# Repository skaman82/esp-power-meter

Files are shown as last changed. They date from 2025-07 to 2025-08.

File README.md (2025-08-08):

# **ESP PowerMeter**

Energy logging und current/voltage meter. Solar panel tester and a Home Assistant MQTT battery sensor
---
Web Interface:
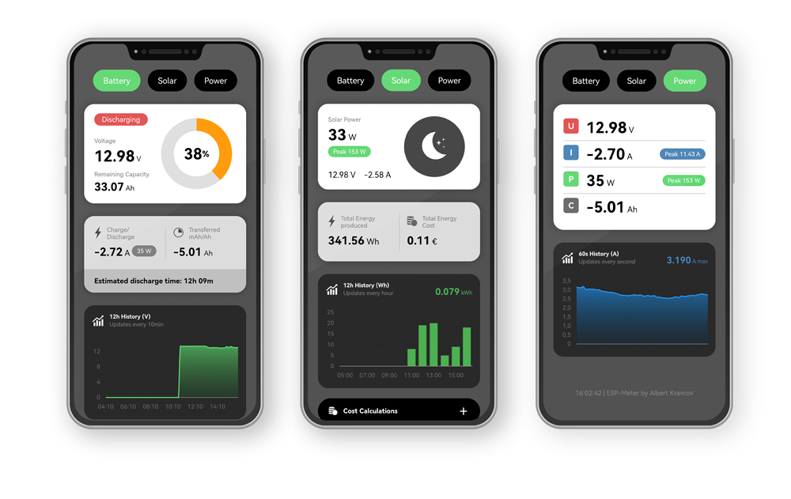
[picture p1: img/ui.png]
UI


## **Features**
- **3 Modes:** Coulometer / Solar Tester / Power Meter  
- **3 Battery Types Supported:** Li-ion, LiPo, LiFePO4  
- Fully configurable with **OLED UI**  
- **Wi-Fi Support:** Access Point mode or join an existing network  
- Additional **Web Interface**  
- **MQTT Support:** can be used as a sensor with Home Assistant  
- **Max Voltage:** 36V (listed 5V BEC supports max. 30V)  

---

## **Parts needed**
- **ESP32-C3 PRO MINI**  
- **5V BEC** (iFlight 5V 2-8S)  
- **INA226 Module** + 3920 5W 2mΩ Shunt (R002)  
 *or* custom INA226 PCB (see Hardware directory)
- **male/female XT60 connectors*
- **1.5" 128x128 I2C OLED Display** *(optional)*  
- **2x Tactile Buttons** *(optional)*
- **Real Time Clock RTC DS3231 module** *(optional)*  
- **3D Printed Case** (see STLs directory)  

## **RTC and NON-RTC Versions**
The main difference to the non-RTC version ist that the RTC version of the code uses an DS3231 real time clock for measurement and displays graph labels with the correct time in the Web-UI. 

---

Device Image:
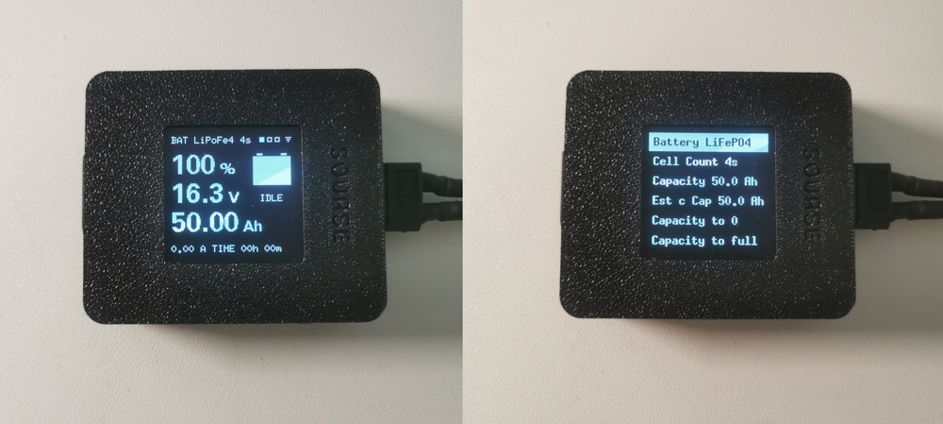
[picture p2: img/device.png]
Device


## **Button Mapping**
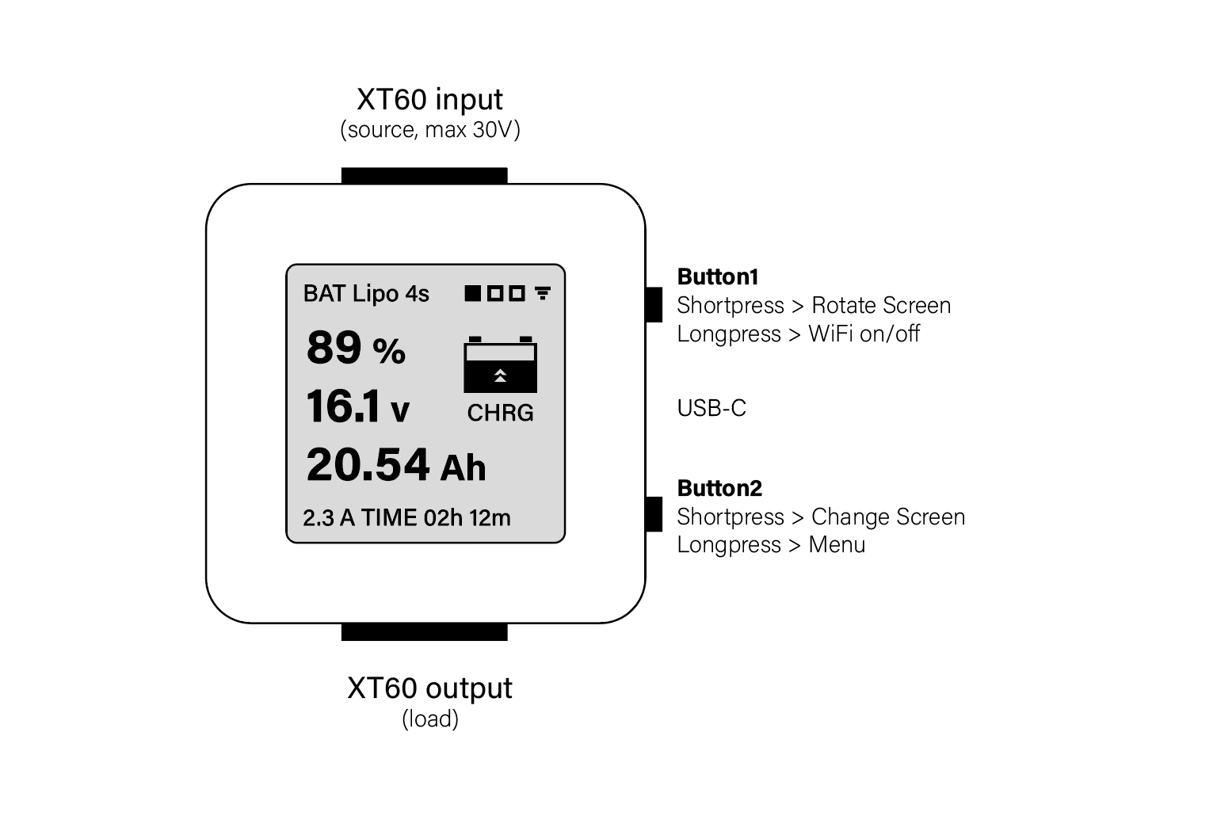
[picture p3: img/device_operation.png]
Buttons


## **MQTT Entities in Home Assistant**
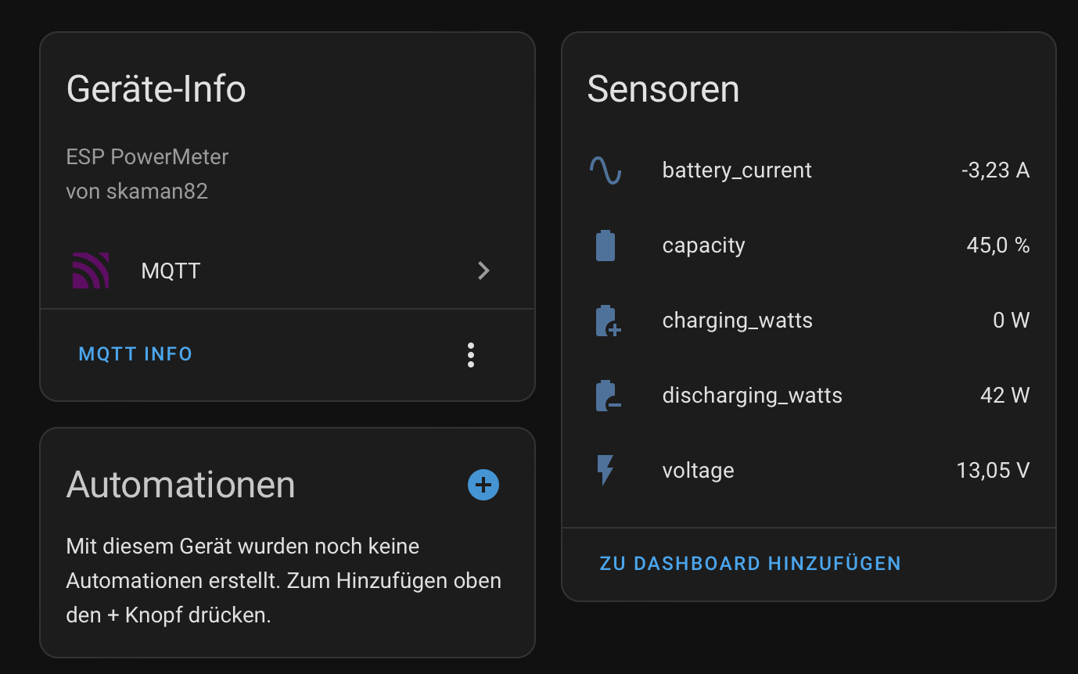
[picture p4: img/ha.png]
MQTT


Custom INA266 Sensor PCB with optional DS3231:
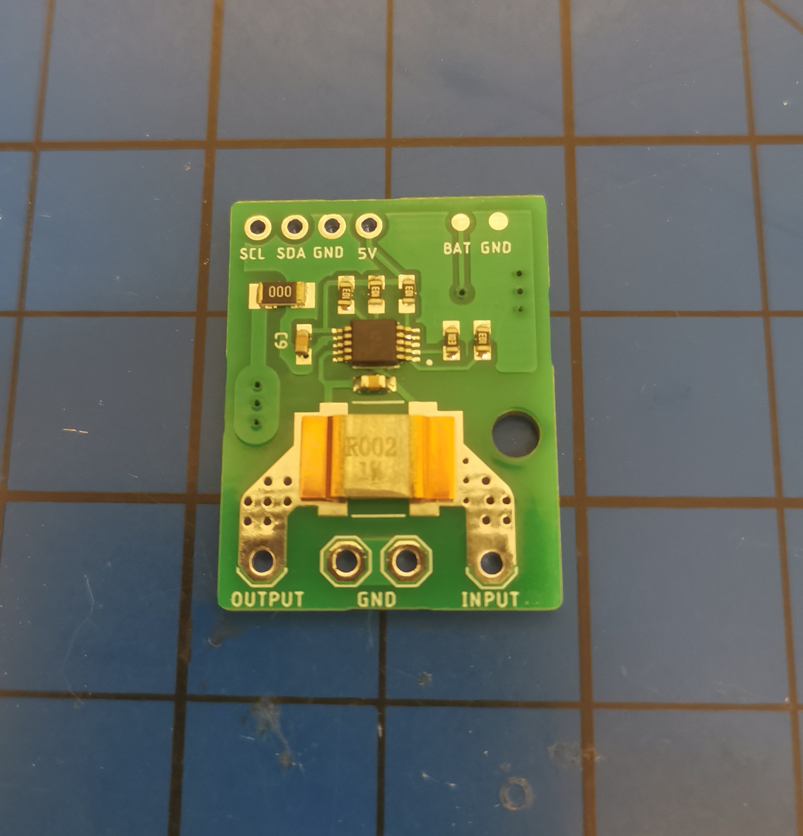
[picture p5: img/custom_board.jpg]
PCB


## **Connection Diagram**
*To be determined (TBD)*  

---

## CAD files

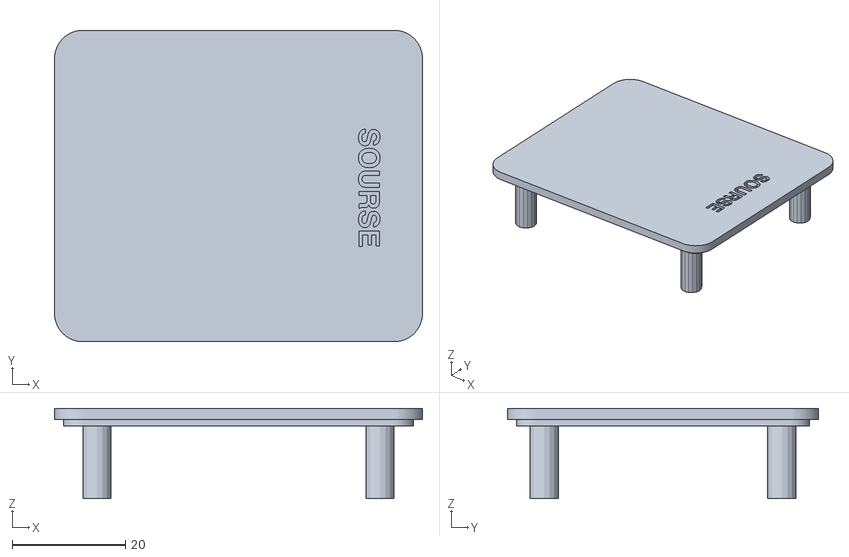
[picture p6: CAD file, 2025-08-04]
STLs/Case_cover_no_screen.stl
65.0 x 55.0 x 15.9

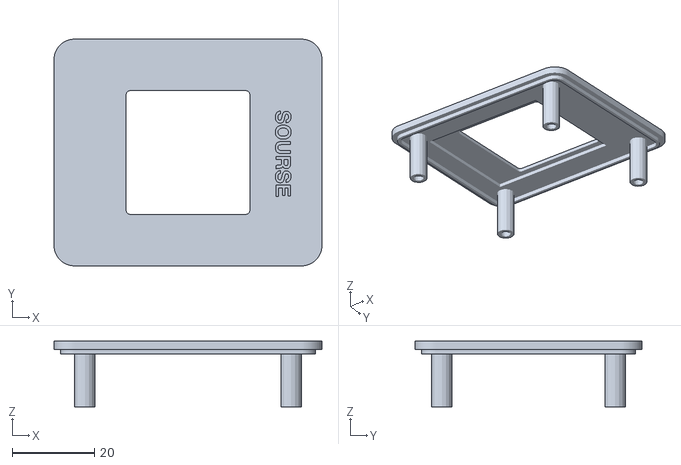
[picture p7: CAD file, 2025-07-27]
STLs/Case_cover.stl
65.0 x 55.0 x 15.9

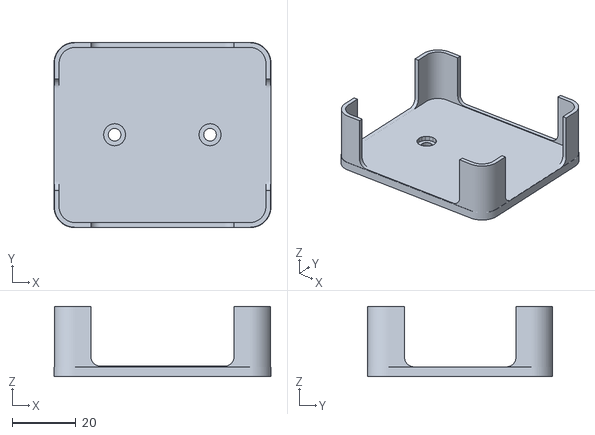
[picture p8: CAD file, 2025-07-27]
STLs/Case_holder.stl
68.2 x 58.2 x 22.0

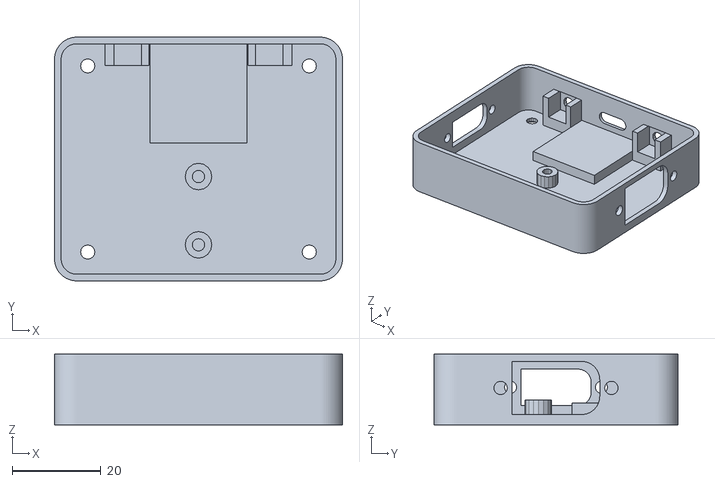
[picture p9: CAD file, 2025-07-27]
STLs/Case.stl
65.0 x 55.0 x 16.0

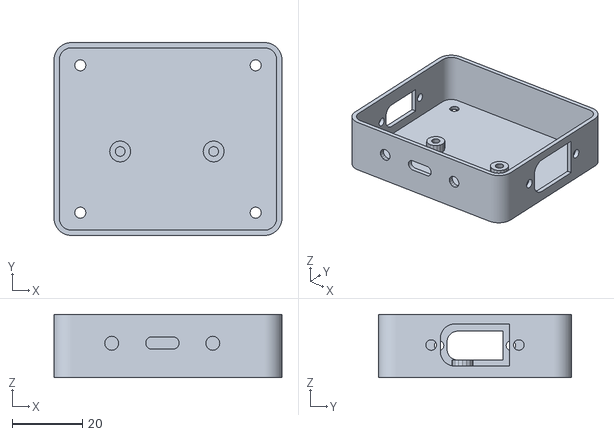
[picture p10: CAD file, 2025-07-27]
STLs/Case_allinone.stl
65.0 x 55.0 x 18.0

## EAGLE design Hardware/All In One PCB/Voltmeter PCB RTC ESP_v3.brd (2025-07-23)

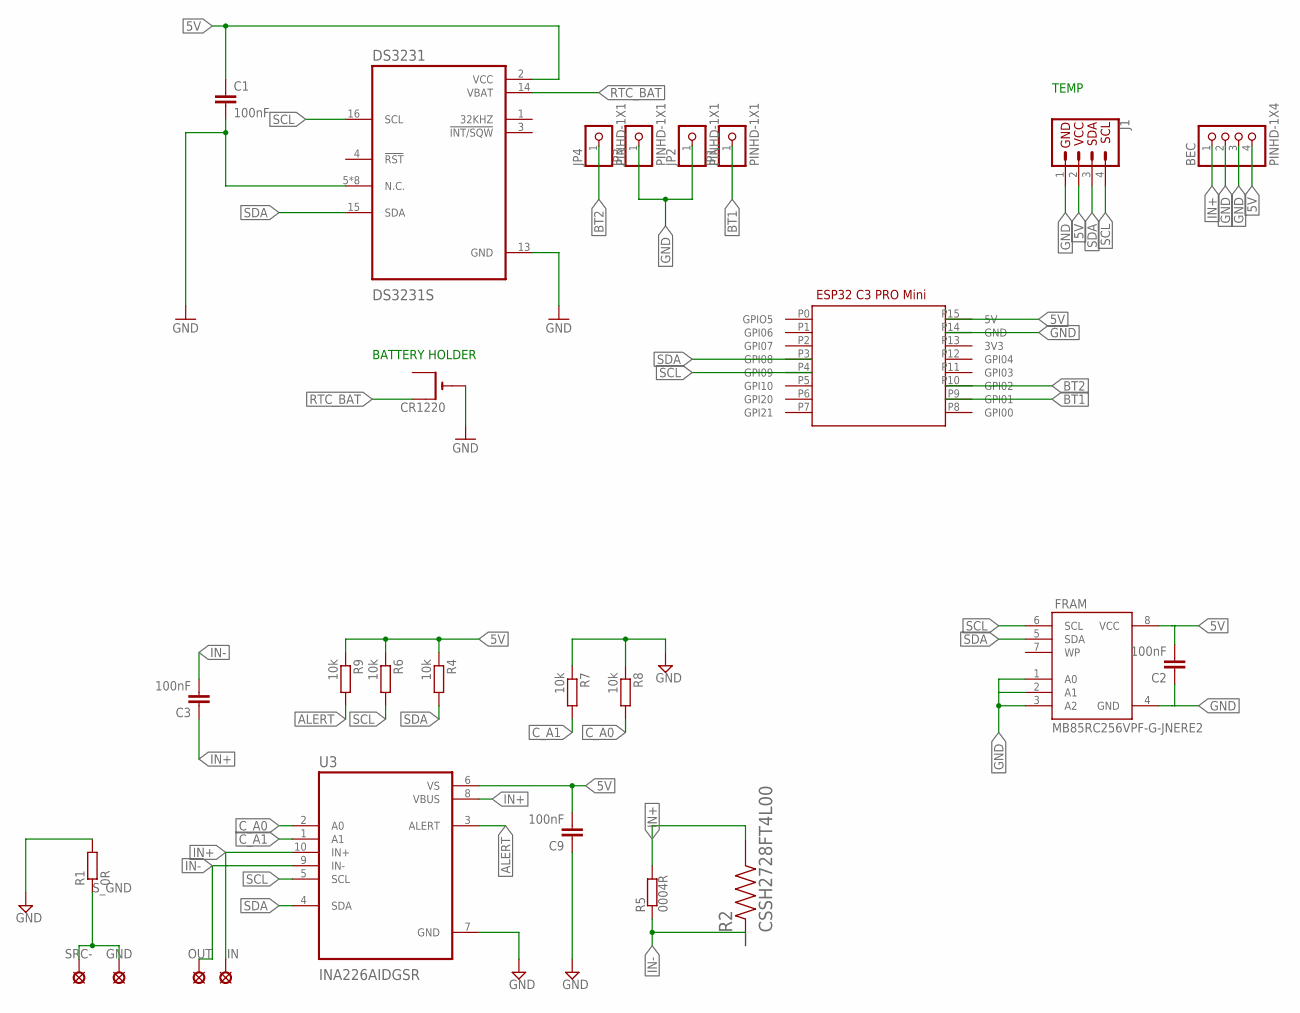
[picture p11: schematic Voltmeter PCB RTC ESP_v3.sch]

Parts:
BEC: PINHD-1X4; 1X04
C1, C2, C3, C9: 100nF; C0603
CR1220: CR1220SMT; CR1220-SMD
DS3231: DS3231S; SOIC127P1032X265-16N
FRAM: MB85RC256VPF-G-JNERE2; SOIC8_208MIL
GND: SE14
IN: SE14
J1: QWIIC_CONNECTORJS-1MM; 1X04_1MM_RA
JP1, JP2, JP3, JP4: PINHD-1X1; 1X01
OUT: SE14
R1: 0R; R1206
R2: CSSH2728FT4L00; RESC6771X124N
R4, R6, R7, R8, R9: 10k; R0603
R5: 0004R; BVS
SRC-: SE14
U3: INA226AIDGSR; SOP50P490X110-10N
U$1: ESP32_C3_PROV1; ESP32_C2_PRO

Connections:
5V: BEC.4, C1.1, C2.2, C9.2, DS3231.2 (VCC), FRAM.8 (VCC), J1.2 (VCC), R4.1, R6.1, R9.1, U3.6 (VS), U$1.P15 (5V)
ALERT: R9.2, U3.3 (ALERT)
BT1: JP1.1, U$1.P9 (GPI01)
BT2: JP4.1, U$1.P10 (GPI02)
C_A0: R8.2, U3.2 (A0)
C_A1: R7.2, U3.1 (A1)
GND: BEC.2, BEC.3, C1.2, C2.1, C9.1, CR1220.-, DS3231.5 (N.C.), DS3231.6 (N.C.), DS3231.7 (N.C.), DS3231.8 (N.C.), DS3231.9 (N.C.), DS3231.10 (N.C.), DS3231.11 (N.C.), DS3231.12 (N.C.), DS3231.13 (GND), FRAM.1 (A0), FRAM.3 (A2), FRAM.4 (GND), J1.1 (GND), JP2.1, JP3.1, R1.2, R7.1, R8.1, U3.7 (GND), U$1.P14 (GND)
IN+: BEC.1, C3.1, IN.MP, R2.2, R5.1, U3.8 (VBUS), U3.10 (IN+)
IN-: C3.2, OUT.MP, R2.1, R5.2, U3.9 (IN-)
RTC_BAT: CR1220.+$1 (+), DS3231.14 (VBAT)
SCL: DS3231.16 (SCL), FRAM.6 (SCL), J1.4 (SCL), R6.2, U3.5 (SCL), U$1.P4 (GPI09)
SDA: DS3231.15 (SDA), FRAM.5 (SDA), J1.3 (SDA), R4.2, U3.4 (SDA), U$1.P3 (GPI08)
S_GND: GND.MP, R1.1, SRC-.MP

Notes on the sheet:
BATTERY HOLDER
TEMP

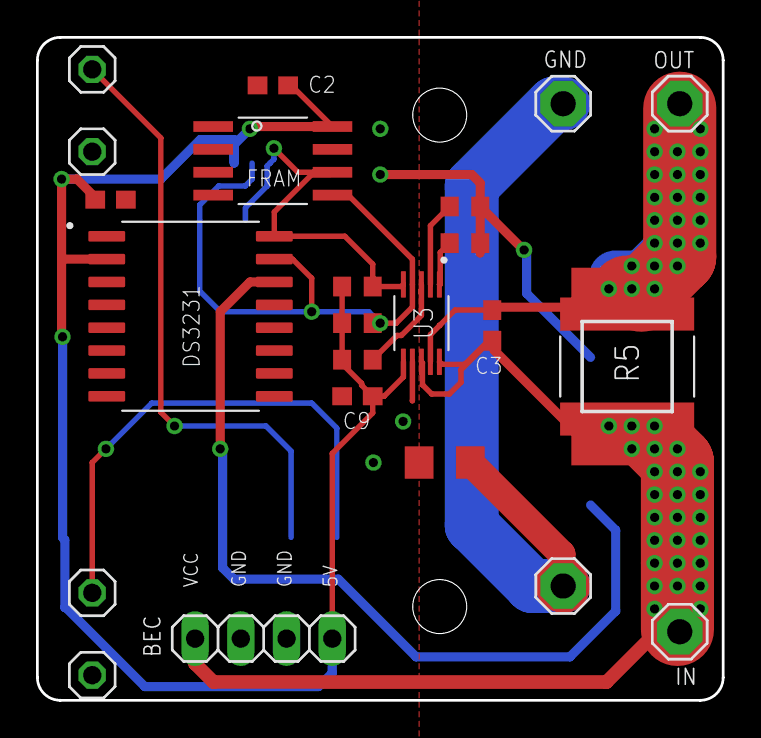
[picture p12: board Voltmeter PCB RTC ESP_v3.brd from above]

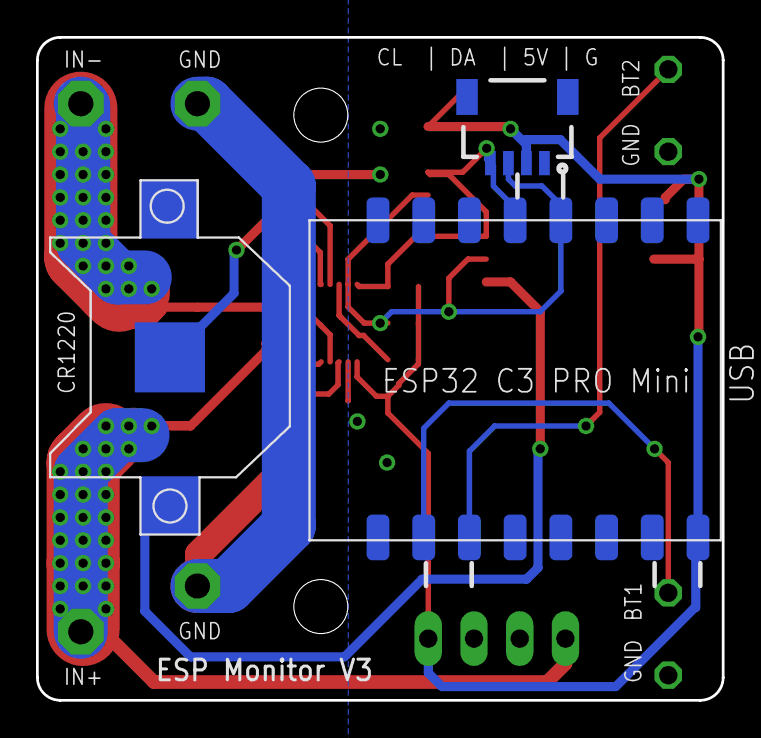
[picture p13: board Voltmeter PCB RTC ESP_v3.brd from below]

Board: 2 copper layers, 38.1 x 36.8 mm, 27 parts (3 on the bottom side), 13 nets.

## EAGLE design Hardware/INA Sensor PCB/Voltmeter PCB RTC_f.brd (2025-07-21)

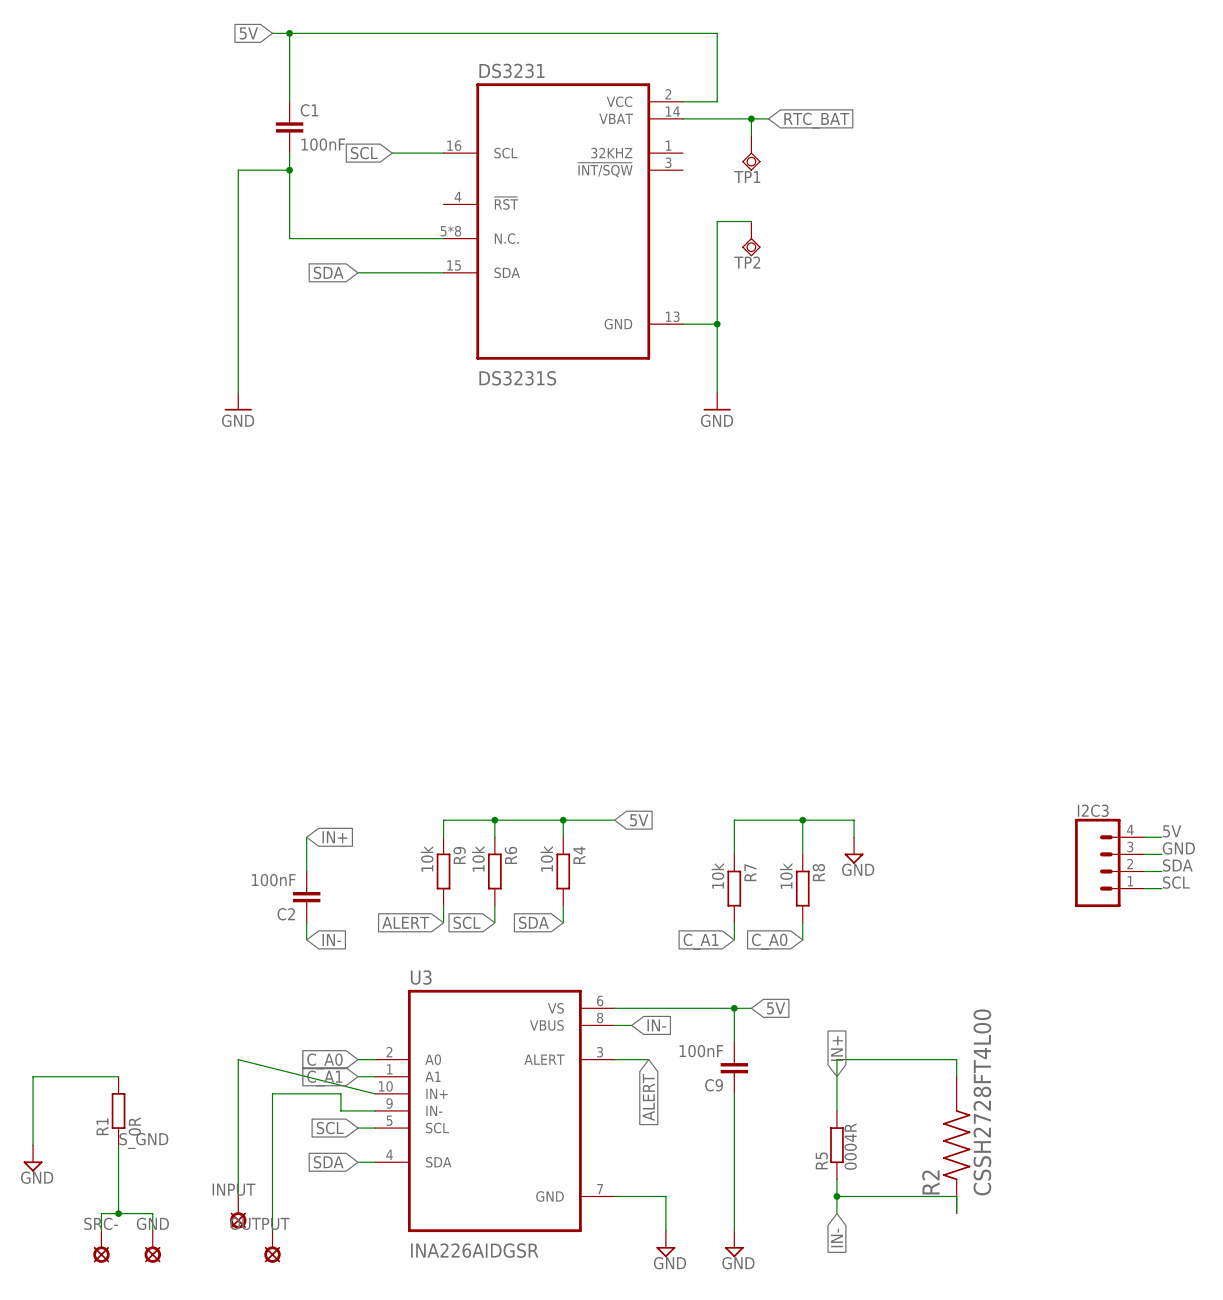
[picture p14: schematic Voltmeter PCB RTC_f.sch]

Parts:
C1, C2, C9: 100nF; C0603
DS3231: DS3231S; SOIC127P1032X265-16N
GND: SE14
I2C3: CONN_041X04_NO_SILK; 1X04_NO_SILK
INPUT: SE14
OUTPUT: SE14
R1: 0R; R1206
R2: CSSH2728FT4L00; RESC6771X124N
R4, R6, R7, R8, R9: 10k; R0603
R5: 0004R; BVS
SRC-: SE14
TP1, TP2: TPSQB1,27; B1,27
U3: INA226AIDGSR; SOP50P490X110-10N

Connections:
5V: C1.1, C9.2, DS3231.2 (VCC), I2C3.4, R4.1, R6.1, R9.1, U3.6 (VS)
ALERT: R9.2, U3.3 (ALERT)
C_A0: R8.2, U3.2 (A0)
C_A1: R7.2, U3.1 (A1)
GND: C1.2, C9.1, DS3231.5 (N.C.), DS3231.6 (N.C.), DS3231.7 (N.C.), DS3231.8 (N.C.), DS3231.9 (N.C.), DS3231.10 (N.C.), DS3231.11 (N.C.), DS3231.12 (N.C.), DS3231.13 (GND), I2C3.3, R1.2, R7.1, R8.1, TP2.TP, U3.7 (GND)
IN+: C2.2, OUTPUT.MP, R2.2, R5.1, U3.9 (IN-)
IN-: C2.1, INPUT.MP, R2.1, R5.2, U3.8 (VBUS), U3.10 (IN+)
RTC_BAT: DS3231.14 (VBAT), TP1.TP
SCL: DS3231.16 (SCL), I2C3.1, R6.2, U3.5 (SCL)
SDA: DS3231.15 (SDA), I2C3.2, R4.2, U3.4 (SDA)
S_GND: GND.MP, R1.1, SRC-.MP

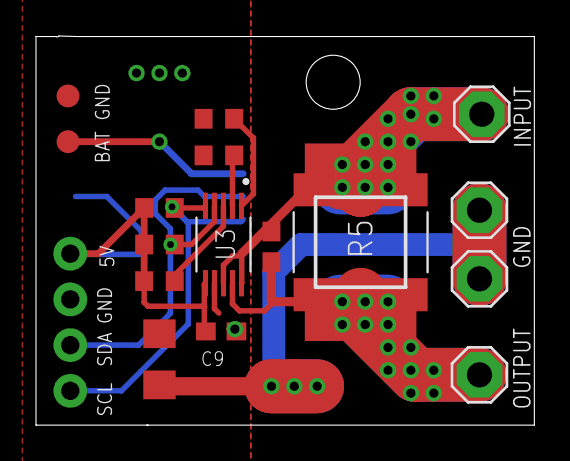
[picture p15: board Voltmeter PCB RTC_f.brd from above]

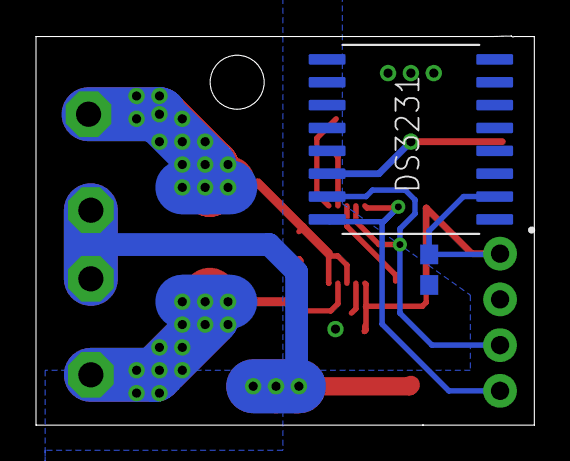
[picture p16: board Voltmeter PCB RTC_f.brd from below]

Board: 2 copper layers, 27.7 x 21.6 mm, 20 parts (2 on the bottom side), 11 nets.

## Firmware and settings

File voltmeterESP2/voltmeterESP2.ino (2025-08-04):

/** NON-RTC VERSION
 * ESP32 Power Meter - Battery Monitor System. Non-RTC Version 
 * Hardware: DFRobot Beetle ESP32-C3 @ 80MHz with INA226 current sensor
 * 
 * Features:
 * - Battery monitoring with INA226 sensor
 * - OLED display with multiple screens
 * - Web interface with real-time data
 * - MQTT integration for Home Assistant
 * - Energy consumption logging
 * - Multiple battery chemistry support (Li-ion, LiPo, LiFePO4)
 */

// ===== INCLUDES =====
#include <WiFi.h>
#include <ESPAsyncWebServer.h>
#include <ESPmDNS.h>
#include <FS.h>
#include <LittleFS.h>
#include <time.h>
#include <Preferences.h> 
#include <INA226_WE.h>
#include <Arduino.h>
#include <Wire.h>
#include <EEPROM.h>
#include <esp_system.h>

// ===== FEATURE TOGGLES =====
#define OLED                  // Enable OLED Display 
//#define MQTT                  // Enable MQTT for Home Assistant
#define WEBSERVER             // Enable Web UI

// ===== DEVICE CONFIGURATION =====
struct DeviceConfig {
    float deviceCurrent = 0.017f;        // 17 mA in normal mode
    float deviceCurrentWifi = 0.050f;    // 50 mA in WiFi Mode
    byte batteryType = 0;                // 0:LiIon; 1:LiPo; 2:LiFePO4
    int cellcount = 4;                   // Battery cell count
    float batteryCapacityAh = 50.00f;    // Full battery capacity in Ah
    byte orientation = 1;                // Screen orientation
    byte screen = 0;                     // Default start screen (0-2)
    byte wifiEnabled = 1;                // WiFi active or not
    float pricePerKWh = 0.305f;          // Price per kWh
};

// ===== NETWORK CONFIGURATION =====
const char* WIFI_SSID = "airport";
const char* WIFI_PASSWORD = "xxx";
const char* AP_PASSWORD = "12345678";

// ===== GLOBAL VARIABLES =====
DeviceConfig config;
Preferences preferences;
char AP_SSID[32];
AsyncWebServer server(80);

// ===== PIN DEFINITIONS =====
#define BUTTON1_PIN 1
#define BUTTON2_PIN 2
#define I2C_ADDRESS 0x40

// ===== HARDWARE OBJECTS =====
#ifdef OLED
#include <U8g2lib.h>
U8G2_SH1107_SEEED_128X128_F_HW_I2C u8g2(U8G2_R0, /* reset=*/ U8X8_PIN_NONE);
#endif

#ifdef MQTT
#include <PubSubClient.h>
const char* MQTT_SERVER = "homeassistant.local";
const int MQTT_PORT = 1883;
const char* MQTT_USER = "mqtt_user";
const char* MQTT_PASS = "mqtt_password";
WiFiClient espClient;
PubSubClient mqttClient(espClient);
#endif

INA226_WE ina226 = INA226_WE(I2C_ADDRESS);

// ===== TIMING VARIABLES =====
struct TimingControl {
    unsigned long previousMillis = 0;
    unsigned long lastSensorMillis = 0;
    unsigned long lastUpdateMicros = 0;
    unsigned long previousMicros = 0;
    unsigned long lastEnergySecond = 0;
    unsigned long lastMqttAttempt = 0;
    unsigned long hourStartMillis = 0;
    unsigned long lastCapacityMinuteMillis = 0;
    unsigned long lastAmpSecondMillis = 0;
    
    const unsigned long SENSOR_INTERVAL = 1000;        // 1 second
    const unsigned long INTERVAL_MICROS = 1000000;     // 1 second in microseconds
    const unsigned long MQTT_RETRY_INTERVAL = 5000;    // 5 seconds
};
TimingControl timing;

// ===== SENSOR DATA STRUCTURE =====
struct SensorData {
    float voltage = 0.0f;
    float current = 0.0f;
    float cellVoltage = 0.0f;
    float capacity = 0.0f;
    float remainingCapacityAh = 0.0f;
    int remainingCapacitymAh = 0;
    int watts = 0;
    int maxWatts = 0;
    float maxCurrent = 0.0f;
    float maxCurrentMin = 0.0f;
    byte currentDirection = 0;  // 0=idle, 1=discharging, 2=charging
    float selfConsumption = 0.0f;
    
    // Energy tracking
    float totalWh = 0.0f;
    float totalKWh = 0.0f;
    float totalPrice = 0.0f;
    float totalUsedmAh = 0.0f;
    double accumulatedWh = 0.0;
    
    // Runtime calculation
    float runtimeHours = 0.0f;
    int hours = 0;
    int minutes = 0;
};
SensorData sensorData;

// ===== UI CONTROL =====
struct UIControl {
    byte menu = 0;
    byte submenu = 0;
    byte menustep = 0;
    byte pressedButton = 0;
    
    // Button handling
    bool button1State = false;
    bool button2State = false;
    unsigned long button1PressTime = 0;
    unsigned long button2PressTime = 0;
    bool button1Handled = false;
    bool button2Handled = false;
    
    const unsigned long LONG_PRESS_TIME = 500;
    
    // Display buffers
    char batteryChars[7] = "000.00";
    char priceChars[6] = "0.000";
    
    byte saved = 0;
    byte reset = 0;
    bool statsSaved = true;
};
UIControl ui;

// ===== EEPROM ADDRESSES =====
struct EEPROMAddresses {
    static const int TYPE = 0;
    static const int CELL = 1;
    static const int CAPACITY = 2;
    static const int PRICE = 6;
    static const int REMAINING_CAP = 10;
    static const int KWH = 14;
    static const int MODE = 18;
    static const int WIFI = 19;
    static const int SCREEN = 30;
    static const int ORIENTATION = 31;
    static const int KWH_HISTORY = 32;
};

// ===== DATA ARRAYS =====
float hourlyKWh[12] = {0};          // Last 12 hours kWh values
float historyCapacity[72] = {0};     // 72 × 10min = 720min = 12h
float historyVoltage[72] = {0};      // Voltage history
float last60Amps[60] = {0};          // Last 60 seconds of amp readings
int capacityIndex = 0;

// ===== BATTERY CURVES =====
// Li-ion battery discharge curve
const int LIION_POINTS = 11;
const float liionVoltage[LIION_POINTS]  = {4.20, 4.10, 4.00, 3.90, 3.80, 3.70, 3.60, 3.50, 3.40, 3.30, 3.20};
const float liionCapacity[LIION_POINTS] = {100,   90,   80,   70,   60,   50,   40,   30,   20,   10,    0};

// LiPo battery discharge curve
const int LIPO_POINTS = 11;
const float lipoVoltage[LIPO_POINTS]  = {4.20, 4.15, 4.05, 3.95, 3.85, 3.75, 3.65, 3.55, 3.45, 3.35, 3.30};
const float lipoCapacity[LIPO_POINTS] = {100,   95,   85,   75,   65,   55,   45,   35,   20,   10,    0};

// LiFePO4 battery discharge curve
const int LIFEPO4_POINTS = 9;
const float lifepo4Voltage[LIFEPO4_POINTS]  = {3.65, 3.45, 3.40, 3.35, 3.30, 3.25, 3.20, 3.10, 2.90};
const float lifepo4Capacity[LIFEPO4_POINTS] = {100,   95,   90,   80,   60,   40,   25,   10,    0};

// ===== FUNCTION DECLARATIONS =====
void initializeSystem();
void initializeSSID();
void initializeHardware();
void initializeEEPROM();
void initializeWiFi();
void initializeWebServer();
void initializeMQTT();

void updateSensorData();
void handleButtons();
void handleEnergyLogging();
float estimateCapacity(float voltage, const float* volts, const float* caps, int size);
void saveConfigToEEPROM();

#ifdef OLED
void updateDisplay();
void drawMainScreen();
void drawPowerScreen();
void drawStatsScreen();
void drawMenuScreen();
void drawCapacityEditScreen();
void drawPriceEditScreen();
void handleButtonInput();
#endif

#ifdef MQTT
void handleMQTT();
void checkMQTTConnection();
void publishSensorData();
void publishDiscoveryMessages();
void publishDiscoveryEntity(const char* name, const char* unit, const char* deviceClass, 
                           const char* icon, const String& deviceInfo, const String& baseTopic);
#endif

void handleWebServer();
void disableWiFiServer();

// ===== MAIN SETUP FUNCTION =====
void setup() {
    Serial.begin(9600);
    Serial.println("ESP32 Power Meter Starting...");
    
    // Initialize all subsystems
    initializeSystem();
    
    Serial.println("System initialization complete!");
}

// ===== MAIN LOOP =====
void loop() {
    // Handle time-critical operations
    handleButtons();
    
    // Handle sensor reading every second
    if (millis() - timing.lastSensorMillis >= timing.SENSOR_INTERVAL) {
        timing.lastSensorMillis = millis();
        updateSensorData();
        handleEnergyLogging();
    }
    
    #ifdef OLED
    handleButtonInput();
    updateDisplay();
    #endif
    
    #ifdef MQTT
    if (config.wifiEnabled && WiFi.status() == WL_CONNECTED) {
        handleMQTT();
    }
    #endif
}

// ===== SYSTEM INITIALIZATION =====
/**
 * Initialize all system components in proper order
 */
void initializeSystem() {
    // Setup pins
    pinMode(BUTTON1_PIN, INPUT_PULLUP);
    pinMode(BUTTON2_PIN, INPUT_PULLUP);
    
    // Initialize subsystems
    initializeSSID();
    
    #ifdef OLED
    initializeEEPROM();
    #endif
    
    initializeHardware();

    if (config.wifiEnabled) {
        initializeWiFi();
        
        #ifdef MQTT
        initializeMQTT();
        #endif
        
        #ifdef WEBSERVER
        initializeWebServer();
        #endif
        
        sensorData.selfConsumption = config.deviceCurrentWifi;
    } else {
        sensorData.selfConsumption = config.deviceCurrent;
    }
    
    // Initialize data arrays
    memset(last60Amps, 0, sizeof(last60Amps));
    memset(historyCapacity, 0, sizeof(historyCapacity));
    memset(historyVoltage, 0, sizeof(historyVoltage));
    memset(hourlyKWh, 0, sizeof(hourlyKWh));
    
    // Initialize energy tracking
    timing.hourStartMillis = millis();
}

/**
 * Generate unique SSID for access point mode
 */
void initializeSSID() {
    preferences.begin("esp32meter", false);
    
    if (!preferences.isKey("ssid")) {
        randomSeed(esp_random());
        int suffix = random(100, 1000);
        snprintf(AP_SSID, sizeof(AP_SSID), "ESP32-Meter %d", suffix);
        preferences.putString("ssid", AP_SSID);
    } else {
        String storedSSID = preferences.getString("ssid", "ESP32-Meter");
        storedSSID.toCharArray(AP_SSID, sizeof(AP_SSID));
    }
    
    preferences.end();
    Serial.println("SSID: " + String(AP_SSID));
}

/**
 * Initialize all hardware components (I2C, INA226, OLED)
 */
void initializeHardware() {
    // Initialize I2C
    Wire.begin();
    
    // Initialize INA226 current sensor
    if (!ina226.init()) {
        Serial.println("ERROR: INA226 initialization failed!");
        return;
    }
    
    // Configure INA226 for optimal performance
    ina226.setAverage(AVERAGE_64);           // Average 64 samples for stability
    ina226.setMeasureMode(CONTINUOUS);       // Continuous measurement mode

    // Shunt resistor configuration - adjust based on your hardware
    // R002 = 2mΩ resistor, max ~41A measurement range
    // R004 = 4mΩ resistor, max ~20A measurement range  
    // R001 = 1mΩ resistor, max ~82A measurement range
    ina226.setResistorRange(0.00198, 20);    // R002 2mOhm resistor, max ~41A
    ina226.waitUntilConversionCompleted();

    Serial.println("INA226 sensor initialized successfully");
    
    #ifdef OLED
    // Initialize OLED display
    u8g2.begin();
    setDisplayOrientation();
    Serial.println("OLED initialized successfully");
    #endif
}

#ifdef OLED
/**
 * Set display orientation based on configuration
 */
void setDisplayOrientation() {
    switch (config.orientation) {
        case 0: u8g2.setDisplayRotation(U8G2_R1); break;
        case 1: u8g2.setDisplayRotation(U8G2_R2); break;
        case 2: u8g2.setDisplayRotation(U8G2_R3); break;
        case 3: u8g2.setDisplayRotation(U8G2_R0); break;
        default: u8g2.setDisplayRotation(U8G2_R2); break;
    }
    u8g2.clear();
}
#endif

/**
 * Load configuration from EEPROM and validate values
 */
void initializeEEPROM() {
    EEPROM.begin(512);
    Serial.println("Loading configuration from EEPROM...");
    
    // Load battery configuration
    config.batteryType = EEPROM.read(EEPROMAddresses::TYPE);
    if (config.batteryType > 2) config.batteryType = 0;
    
    config.cellcount = EEPROM.read(EEPROMAddresses::CELL);
    if (config.cellcount == 0 || config.cellcount > 6) config.cellcount = 1;
    
    // Load and validate float values
    EEPROM.get(EEPROMAddresses::CAPACITY, config.batteryCapacityAh);
    if (isnan(config.batteryCapacityAh) || config.batteryCapacityAh <= 0 || config.batteryCapacityAh > 1000) {
        config.batteryCapacityAh = 1.0f;
        EEPROM.put(EEPROMAddresses::CAPACITY, config.batteryCapacityAh);
    }
    
    EEPROM.get(EEPROMAddresses::PRICE, config.pricePerKWh);
    if (isnan(config.pricePerKWh) || config.pricePerKWh < 0 || config.pricePerKWh > 1000) {
        config.pricePerKWh = 0.0f;
        EEPROM.put(EEPROMAddresses::PRICE, config.pricePerKWh);
    }
    
    // Load UI settings
    config.wifiEnabled = EEPROM.read(EEPROMAddresses::WIFI);
    if (config.wifiEnabled > 1) {
        config.wifiEnabled = 0;
        EEPROM.write(EEPROMAddresses::WIFI, config.wifiEnabled);
    }
    
    config.screen = EEPROM.read(EEPROMAddresses::SCREEN);
    if (config.screen > 2) config.screen = 0;
    
    config.orientation = EEPROM.read(EEPROMAddresses::ORIENTATION);
    if (config.orientation > 3) config.orientation = 0;
    
    // Load sensor data
    EEPROM.get(EEPROMAddresses::REMAINING_CAP, sensorData.remainingCapacityAh);
    if (isnan(sensorData.remainingCapacityAh) || sensorData.remainingCapacityAh < 0) {
        sensorData.remainingCapacityAh = config.batteryCapacityAh;
        EEPROM.put(EEPROMAddresses::REMAINING_CAP, sensorData.remainingCapacityAh);
    }
    
    EEPROM.get(EEPROMAddresses::KWH, sensorData.totalKWh);
    if (isnan(sensorData.totalKWh) || sensorData.totalKWh < 0 || sensorData.totalKWh > 100000) {
        sensorData.totalKWh = 0.0f;
        EEPROM.put(EEPROMAddresses::KWH, sensorData.totalKWh);
    }
    
    EEPROM.commit();
    
    // Calculate derived values
    sensorData.remainingCapacitymAh = sensorData.remainingCapacityAh * 1000.0f;
    sensorData.totalWh = sensorData.totalKWh * 1000.0f;
    sensorData.totalPrice = sensorData.totalKWh * config.pricePerKWh;
    
    Serial.println("Configuration loaded successfully");
    Serial.println("Battery Type: " + String(config.batteryType));
    Serial.println("Cell Count: " + String(config.cellcount));
    Serial.println("Capacity: " + String(config.batteryCapacityAh) + " Ah");
    Serial.println("Price/kWh: " + String(config.pricePerKWh));
    Serial.println("Orientation: " + String(config.orientation));
    Serial.println("Screen: " + String(config.screen));
}

/**
 * Initialize WiFi in dual mode (AP + Station)
 */
void initializeWiFi() {
    WiFi.mode(WIFI_AP_STA);
    
    // Start Access Point
    WiFi.softAP(AP_SSID, AP_PASSWORD);
    Serial.println("Access Point: " + String(AP_SSID));
    Serial.println("AP IP: " + WiFi.softAPIP().toString());
    
    // Try to connect to existing WiFi
    WiFi.begin(WIFI_SSID, WIFI_PASSWORD);
    Serial.print("Connecting to WiFi");
    
    int retry = 0;
    while (WiFi.status() != WL_CONNECTED && retry < 20) {
        delay(500);
        Serial.print(".");
        retry++;
    }
    
    if (WiFi.status() == WL_CONNECTED) {
        Serial.println("\nWiFi connected: " + WiFi.localIP().toString());
    } else {
        Serial.println("\nWiFi connection failed - AP mode only");
    }
}

#ifdef MQTT
/**
 * Initialize MQTT client for Home Assistant integration
 */
void initializeMQTT() {
    mqttClient.setServer(MQTT_SERVER, MQTT_PORT);
    mqttClient.setKeepAlive(60);
    mqttClient.setBufferSize(512);
    Serial.println("MQTT client initialized");
}
#endif

/**
 * Initialize web server and API endpoints
 */
void initializeWebServer() {
    if (!LittleFS.begin(true)) {
        Serial.println("Failed to mount LittleFS");
        return;
    }
    
    // Serve static files
    server.serveStatic("/", LittleFS, "/").setDefaultFile("index.html");
    
    // API endpoint for sensor data
    server.on("/data", HTTP_GET, [](AsyncWebServerRequest *request) {
        String json = buildSensorDataJSON();
        request->send(200, "application/json", json);
    });
    
    // API endpoint for screen control
    server.on("/setScreen", HTTP_POST, [](AsyncWebServerRequest *request) {
        if (request->hasParam("value", true)) {
            String value = request->getParam("value", true)->value();
            config.screen = value.toInt();
            request->send(200, "text/plain", "OK");
        } else {
            request->send(400, "text/plain", "Missing 'value'");
        }
    });
    
    server.onNotFound([](AsyncWebServerRequest *request) {
        request->send(404, "text/plain", "404: Not Found");
    });
    
    server.begin();
    Serial.println("Webserver started");
}

/**
 * Build JSON string with all sensor data for web interface
 */
String buildSensorDataJSON() {
    String json = "{";
    json += "\"batteryType\":" + String(config.batteryType) + ",";
    json += "\"cellcount\":" + String(config.cellcount) + ",";
    json += "\"watts\":" + String(sensorData.watts) + ",";
    json += "\"Ampere\":" + String(sensorData.current, 2) + ",";
    json += "\"cur_dir\":" + String(sensorData.currentDirection) + ",";
    json += "\"voltage\":" + String(sensorData.voltage, 2) + ",";
    json += "\"capacity\":" + String(sensorData.capacity, 2) + ",";
    json += "\"batteryCapacityAh\":" + String(config.batteryCapacityAh, 2) + ",";
    json += "\"remainingCapacityAh\":" + String(sensorData.remainingCapacityAh, 2) + ",";
    json += "\"pricePerKWh\":" + String(config.pricePerKWh, 3) + ",";
    json += "\"totalWh\":" + String(sensorData.totalWh, 2) + ",";
    json += "\"totalKWh\":" + String(sensorData.totalKWh, 3) + ",";
    
    // Dynamic energy display
    if (abs(sensorData.totalUsedmAh) >= 1000.0f) {
        json += "\"usedEnergy\":" + String(sensorData.totalUsedmAh / 1000.0f, 2) + ",";
        json += "\"usedUnit\":\"Ah\",";
    } else {
        json += "\"usedEnergy\":" + String(sensorData.totalUsedmAh, 0) + ",";
        json += "\"usedUnit\":\"mAh\",";
    }
    
    json += "\"screen\":" + String(config.screen) + ",";
    json += "\"maxWatts\":" + String(sensorData.maxWatts) + ",";
    json += "\"maxA\":" + String(sensorData.maxCurrent, 2) + ",";
    json += "\"maxA_min\":" + String(sensorData.maxCurrentMin, 2);
    
    // Add array data
    json += ",\"hourlyKWh\":[";
    for (int i = 0; i < 12; i++) {
        json += String(hourlyKWh[i], 3);
        if (i < 11) json += ",";
    }
    json += "]";
    
    json += ",\"historyCapacity\":[";
    for (int i = 0; i < 72; i++) {
        json += String(static_cast<int>(historyCapacity[i]));
        if (i < 71) json += ",";
    }
    json += "]";
    
    json += ",\"historyVoltage\":[";
    for (int i = 0; i < 72; i++) {
        json += String(historyVoltage[i], 2);
        if (i < 71) json += ",";
    }
    json += "]";
    
    json += ",\"last60Amps\":[";
    for (int i = 0; i < 60; i++) {
        json += String(last60Amps[i], 2);
        if (i < 59) json += ",";
    }
    json += "]";
    
    json += "}";
    return json;
}
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

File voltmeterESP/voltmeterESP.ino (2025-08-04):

#include <WiFi.h>
#include <ESPAsyncWebServer.h>
#include <ESPmDNS.h>
#include <FS.h>
#include <LittleFS.h>
#include <time.h>
#include <Preferences.h>  
Preferences preferences;  // Declare this globallychar AP_SSID[32];
#include <INA226_WE.h>
#include <Arduino.h>
#include <Wire.h>
#include <EEPROM.h>
#include <esp_system.h>


//CONFIG START >>>>>>>>>>>>>>>>>>>>>>>>>>>>>>>>>>>>>>>>>>>>>>>>>>>>>>>>>>>>>>>>>>>>>>>>

#define OLED  // Enable OLED Display 
#define MQTT  // Enable MQTT for Home Assistant
#define WEBSERVER    // Enable Web UI



//Device Settings START (No need to configure when using an OLED screen and buttons)
float deviceCurrent = 0.017;      // 17 mA in normal mode
float deviceCurrentWifi = 0.050;  // 50 mA in WiFi Mode
byte batteryType = 0;             // 0:LiIon; 1:LiPo; 2:LiFePO4;
int cellcount = 4;                // define Cellcount of the Li-Ion battery
float batteryCapacityAh = 50;     // Full battery capacity in Ah eg 6.6 Ah
byte orientation = 1;             // Screen orientation
byte screen = 0;                  // default start screen (0-2)
byte wifiEnabled = 1;             // WiFi active or not
float pricePerKWh = 0.305;         // 30.5 cents per kWh

//Device Settings END 

#ifdef OLED
#include <U8g2lib.h>
//OLED SELECTION (Uncomment the right one for you)
//U8G2_SSD1306_128X64_NONAME_F_HW_I2C u8g2(U8G2_R0, /* reset=*/ U8X8_PIN_NONE);
//U8G2_SH1106_128X64_NONAME_F_HW_I2C u8g2(U8G2_R0, /* reset=*/ U8X8_PIN_NONE);
//U8G2_SH1107_PIMORONI_128X128_1_HW_I2C u8g2(U8G2_R0, /* reset=*/8);
U8G2_SH1107_SEEED_128X128_F_HW_I2C u8g2(U8G2_R0, /* reset=*/ U8X8_PIN_NONE);
#endif

// ===== NETWORK CONFIGURATION =====
const char* WIFI_SSID = "airport";
const char* WIFI_PASSWORD = "babylon5";
const char* AP_PASSWORD = "12345678";

#ifdef MQTT
#include <PubSubClient.h>
//const char* mqtt_server = "192.168.4.2";  // Your Mac's IP in AP network
const char* mqtt_server = "homeassistant.local";  // or IP of HA
const int mqtt_port = 1883;
const char* mqtt_user = "mqtt_user";
const char* mqtt_pass = "mqtt_password";

WiFiClient espClient;
PubSubClient client(espClient);
#endif

//CONFIG END >>>>>>>>>>>>>>>>>>>>>>>>>>>>>>>>>>>>>>>>>>>>>>>>>>>>>>>>>>>>>>>>>>>>>>>>



char AP_SSID[32];
// Create server on port 80
static AsyncWebServer server(80);

#define BUTTON1_PIN 1
#define BUTTON2_PIN 2

float selfconsumption;

float remainingCapacityAh = 0;
int remainingCapacitymAh = 0;
unsigned long previousMillis = 0;
const unsigned long interval = 500;  // Interval (500 ms)
const unsigned long sensorInterval = 1000;
unsigned long lastMqttAttempt = 0;
const unsigned long mqttRetryInterval = 5000;

const unsigned long longPressTime = 500; // milliseconds
bool button1State = false;
bool button2State = false;
unsigned long button1PressTime = 0;
unsigned long button2PressTime = 0;
bool button1Handled = false;
bool button2Handled = false;
byte pressedbt = 0;

float runtimeHours = 0;
int hours = 0;
int minutes = 0;
float totalWh = 0;
float totalKWh = 0.0;
float totalPrice = 0;

byte menu = 0;
byte submenu = 0;
byte menustep = 0;

#define I2C_ADDRESS 0x40
unsigned long lastUpdateTime = millis(); // track last update time
unsigned long bootTime = millis();
unsigned long lastSensorMillis = 0;

unsigned long lastUpdateMicros = 0;
unsigned long previousMicros = 0;

const unsigned long intervalMicros = 1000000;  // 950 ms in microseconds 950000 +3.3% (30400) = 980400 - old 990100
//CALIBRATE THIS VALUE TO GET ACCURATE MAH COUNT

char batteryChars[7] = "000.00"; // 6 chars + null terminator
char priceChars[6] = "0.000";  // Format: "0,000"

byte cur_dir = 0;

int watts = 0;
int maxWatts = 0;
float Ampere = 0;
float voltage = 0;
float cellvolt = 0;
float capacity = 0;

float shuntVoltage_mV = 0.0;
float loadVoltage_V = 0.0;
float busVoltage_V = 0.0;
float current_A = 0.0;
float power_W = 0.0;
int mAmpere = 0;
float totalUsedmAh = 0;

//SETTINGS
int typeAddress = 0;
int cellAddress = 1;
int cap_Address = 2;
int price_Address = 6;
int remcap_Address = 10;
int kwh_Address = 14; //kwh produced - price can be calculated from that
int mode_Address = 18;
int wifi_Address = 19;
int screen_Address = 30; // Next safe address after existing ones
int orientation_Address = 31;
int kwhHistory_Address = 32;  // Move forward by 2 bytes to make room

byte saved = 0;
byte reset = 0;
bool statsSaved = true;


// Energy tracking
unsigned long lastEnergySecondMillis = 0;
unsigned long hourStartMillis = 0;
float accumulatedWh = 0;
float hourlyKWh[12] = {0};  // stores last 12 hours kWh values
float historyCapacity[72];  // 72 × 10min = 720min = 12h
float historyVoltage[72] = {0};
unsigned long lastCapacityMinuteMillis = 0;
int capacityIndex = 0;

float maxA = 0.0;
float maxA_min = 0.0;
float last60Amps[60];  // Stores last 60 seconds of amp readings (1 per sec)
unsigned long lastAmpSecondMillis = 0;




// Li-ion (typical)
const int liionPoints = 11;
const float liionVoltage[liionPoints]  = {4.20, 4.10, 4.00, 3.90, 3.80, 3.70, 3.60, 3.50, 3.40, 3.30, 3.20};
const float liionCapacity[liionPoints] = {100,   90,   80,   70,   60,   50,   40,   30,   20,   10,    0};

// LiPo (similar to Li-ion, but slightly different tail)
const int lipoPoints = 11;
const float lipoVoltage[lipoPoints]  = {4.20, 4.15, 4.05, 3.95, 3.85, 3.75, 3.65, 3.55, 3.45, 3.35, 3.30};
const float lipoCapacity[lipoPoints] = {100,   95,   85,   75,   65,   55,   45,   35,   20,   10,    0};

// LiFePO₄ (very flat plateau)
const int lifepo4Points = 9;
const float lifepo4Voltage[lifepo4Points]  = {3.65, 3.45, 3.40, 3.35, 3.30, 3.25, 3.20, 3.10, 2.90};
const float lifepo4Capacity[lifepo4Points] = {100,   95,   90,   80,   60,   40,   25,   10,    0};

INA226_WE ina226 = INA226_WE(I2C_ADDRESS);

// Sensor data structure
struct SensorData {
  float voltage = 0.0;
  float capacity = 0.0;
  float Ampere = 0.0;
  int watts = 0;
  byte cur_dir = 0; // 0 = idle, 1 = discharging, 2 = charging
  
  // Calculated values based on your logic
  float soc = 0.0;
  float charging_watts = 0.0;
  float discharging_watts = 0.0;
  float battery_voltage = 0.0;
  float battery_current = 0.0;
};

SensorData sensorData;

// Helper to convert __TIME__ (e.g. "14:33:12") to a unique number
int getCompileTimeSeed() {
  const char* timeStr = __TIME__; // "HH:MM:SS"
  int seed = 0;
  seed += (timeStr[0] - '0') * 36000;
  seed += (timeStr[1] - '0') * 3600;
  seed += (timeStr[3] - '0') * 600;
  seed += (timeStr[4] - '0') * 60;
  seed += (timeStr[6] - '0') * 10;
  seed += (timeStr[7] - '0');
  return seed % 900 + 100; // Ensure it's 3-digit
}



#ifdef MQTT
/**
 * Initialize MQTT client for Home Assistant integration
 * Sets up connection parameters and buffer sizes
 */
void initializeMQTT() {
  client.setServer(mqtt_server, mqtt_port);
  client.setKeepAlive(60);
  client.setBufferSize(512); // Increase buffer size for larger messages
  Serial.println("MQTT client initialized");
}
#endif
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

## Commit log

2025-07-23 PCB Update
    [Voltmeter PCB RTC ESP_v3.brd, Voltmeter PCB RTC ESP_v3.sch]
2025-07-30 updates
    - MQTT functionality
    - favicon fix
    - OLED display + buttons are now optional
    [voltmeterESP.ino, voltmeterESP_RTC.ino]
2025-08-04 new stl
    [Case_cover_no_screen.stl]

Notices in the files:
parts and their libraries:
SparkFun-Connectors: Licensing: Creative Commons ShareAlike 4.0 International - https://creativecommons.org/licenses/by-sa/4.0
